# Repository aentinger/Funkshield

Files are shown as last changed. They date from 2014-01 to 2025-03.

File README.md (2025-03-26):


💾 Funkshield
==============



# 📸 Image

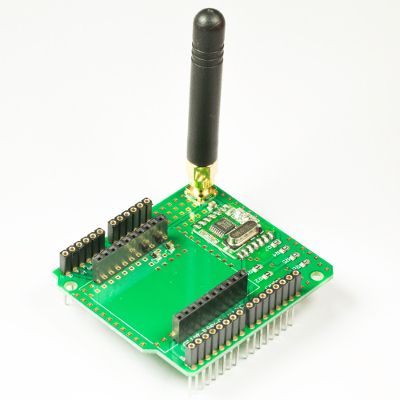
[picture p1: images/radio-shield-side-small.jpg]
LXRobotics P6 Funkshield


# 📂 Description

The Radio Shield provides an easy way to enable wireless communication between two or more Arduinos. Additionally the Radioshield has a Childboard connector socket which allows the Radio Shield to be further upgraded with sensors/actuators, e.g. a gas sensor, temperature sensor or a relay switch. A possible application would be temperature monitoring of all rooms of a house/appartment and performing an efficient regulation of the heating based on the measured data. For an quick and easy start, a open source Arduino library with sample programs is available.

**Features**

* Enables easy wireless communication with other Arduinos
* Usage of the popular RFM12B HF-Transceiver
* Frequency range: 433 MHz ISM-Band
* Childboard-Base for integration of further LXRobotics Childboards (e.g. gas sensor, temperature sensor, relay switch)
* Antenna with 2dbi gain
* Output power is selectable in 3 db steps ranging from 0 dbm to -21 dbm
* Third-Party-Arduino Library available for control with example programms

# 🎥 [Video](images/funkshield_demo.mp4)

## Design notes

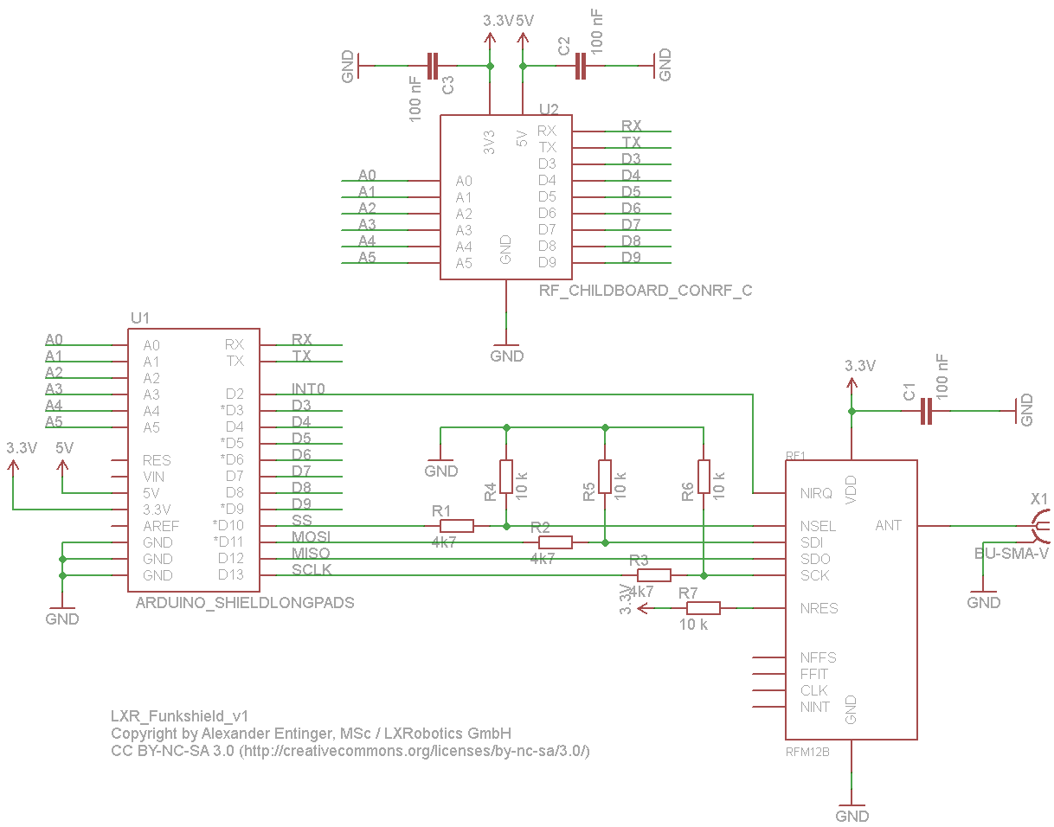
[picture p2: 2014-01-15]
hardware/lxr_funkshield_v1.png

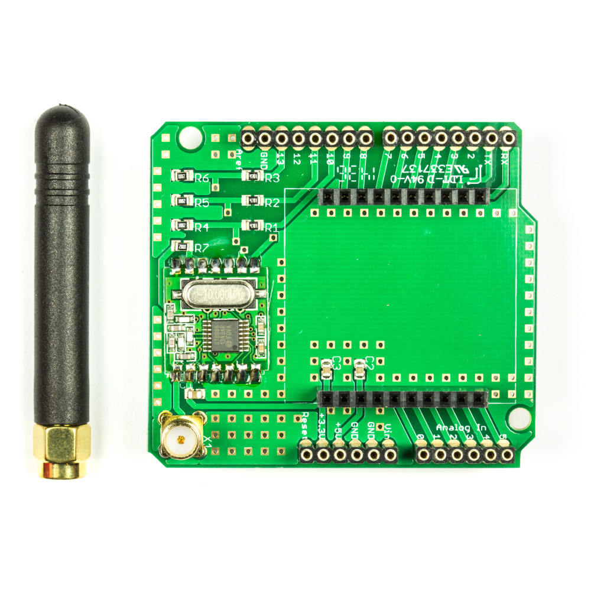
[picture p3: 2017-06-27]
images/radio-shield-top-large.jpg

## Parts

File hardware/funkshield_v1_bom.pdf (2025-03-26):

Menge | Schaltplan | Bezeichnung | Farnell/Conrad Bestell Nummer | Preis (1 Stück) | Gesamtpreis | Wird bestückt | Footprint | Säckchen
1 | RF1 | RFM12B-Klon RF SOLUTIONS - ALPHA-TRX433S | 1718689 | € 5,88 | € 5,88 | | | S1
1 | | 433 MHz Stab-Antenne kurz | 2305893 | € 4,88 | € 4,88 | | | S2
1 | X1 | SMA-Buchse für Leiterplattenmontage | 1248990 | € 1,83 | € 1,83 | | | S2
3 | R1, R2, R3 | 4k7, 0805, SMD Widerstand | 1469923 | € 0,02 | € 0,07 | x
4 | R4, R5, R6, R7 | 10k, 0805, SMD Widerstand | 1469856 | € 0,02 | € 0,09 | x
3 | C1, C2, C3 | 100 nF, 0805, SMD Kondensator | 1759144 | € 0,01 | € 0,03 | x
2 | U2 | RF Childboard Connector Female | 1593464 | € 1,52 | € 3,04 | | | S2
1 | Satz Arduino Stiftleisten | ELV | € | 0,75 | € | 0,75 | S2 | http://www.elv.at/buchsenleisten-set-fuer-arduino-boards.html
| | | Summe | | € | 16,57

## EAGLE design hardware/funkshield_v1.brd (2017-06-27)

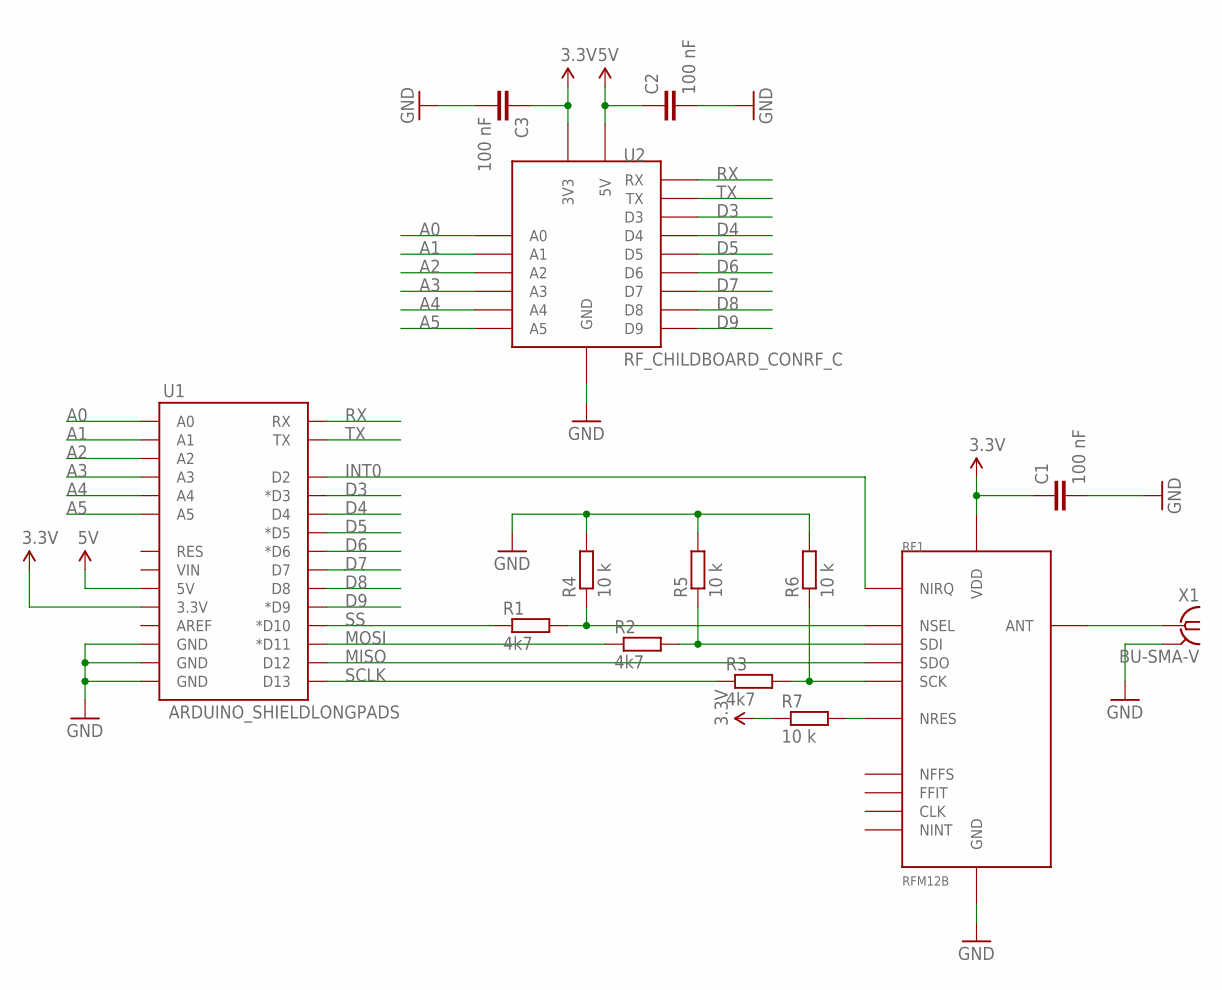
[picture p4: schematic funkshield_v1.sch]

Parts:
C1, C2, C3: 100 nF; C0805
R1, R2, R3: 4k7; M0805
R4, R5, R6, R7: 10 k; M0805
RF1: RFM12B
U1: ARDUINO_SHIELDLONGPADS; DUEMILANOVE_SHIELD_LONGPADS
U2: RF_CHILDBOARD_CONRF_C; RF_CHILDBOARD_CON
X1: BU-SMA-V

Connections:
3.3V: C1.1, C3.1, R7.1, RF1.VDD, U1.3.3V, U2.3V3
5V: C2.1, U1.5V, U2.5V
A0: U1.A0, U2.A0
A1: U1.A1, U2.A1
A2: U1.A2, U2.A2
A3: U1.A3, U2.A3
A4: U1.A4, U2.A4
A5: U1.A5, U2.A5
D3: U1.D3 (*D3), U2.D3
D4: U1.D4, U2.D4
D5: U1.D5 (*D5), U2.D5
D6: U1.D6 (*D6), U2.D6
D7: U1.D7, U2.D7
D8: U1.D8, U2.D8
D9: U1.D9 (*D9), U2.D9
GND: C1.2, C2.2, C3.2, R4.2, R5.2, R6.2, RF1.GND, RF1.GND1 (GND), U1.GND@0 (GND), U1.GND@1 (GND), U1.GND@2 (GND), U2.GND, U2.GND1 (GND), U2.GND2 (GND), X1.2 (GND), X1.3 (GND), X1.4 (GND), X1.5 (GND)
INT0: RF1.NIRQ, U1.D2
MISO: RF1.SDO, U1.D12
MOSI: R2.1, U1.D11 (*D11)
unnamed: R1.2, R4.1, RF1.NSEL
unnamed: R2.2, R5.1, RF1.SDI
unnamed: R3.2, R6.1, RF1.SCK
unnamed: R7.2, RF1.NRES
unnamed: RF1.ANT, X1.1
RX: U1.RX, U2.RX
SCLK: R3.1, U1.D13
SS: R1.1, U1.D10 (*D10)
TX: U1.TX, U2.TX

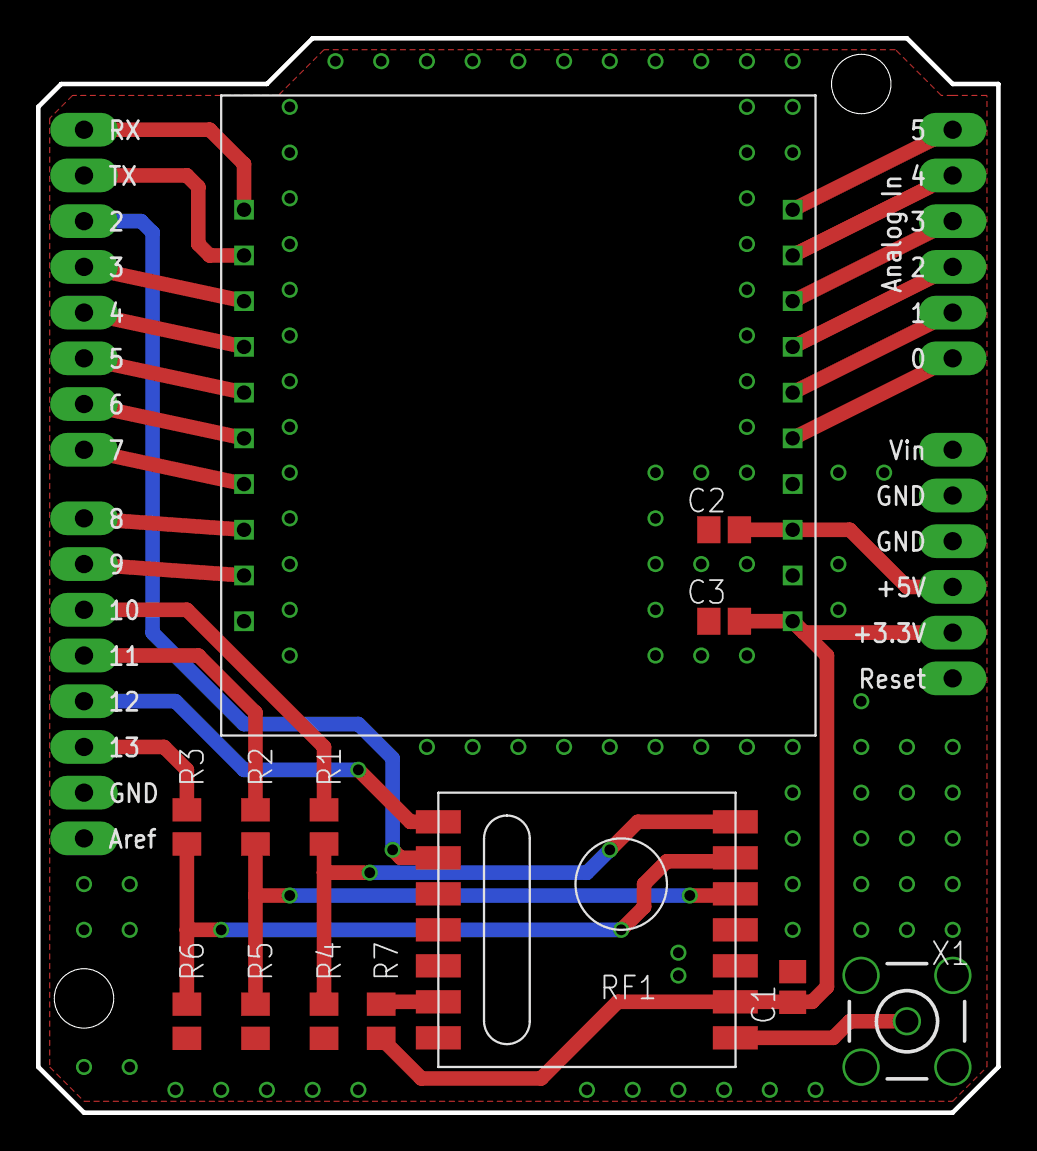
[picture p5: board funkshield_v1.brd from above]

Board: 2 copper layers, 53.3 x 59.7 mm, 14 parts (0 on the bottom side), 28 nets.

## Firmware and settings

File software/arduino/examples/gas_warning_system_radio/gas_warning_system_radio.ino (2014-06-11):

/** 
 * @author Alexander Entinger MSc, LXRobotics
 * @brief this file demonstrates how to use the LXR_CB_Gas_Sensor library in combination with an lxrobotics funkshield too form a wireless gas warning system network - Attention: This is not a calibrated nor a certified smoke/gas/whatever detector. Therefor it can never replace a "real" smoke/gas/.. warning system.
 * @file gas_warning_system_radio.ino
 * @license Attribution-NonCommercial-ShareAlike 3.0 Unported (CC BY-NC-SA 3.0) ( http://creativecommons.org/licenses/by-nc-sa/3.0/ )
 */

#include "LXR_CB_Gas_Sensor.h"
#include "RFM12B.h"
#include "avr/sleep.h"

#define NODEID        1  // Network ID of this unit -> Needs to be different for every node 0 to 127
#define NETWORKID    99  // Network ID
#define GATEWAYID     0  // BROADCAST

// Need an instance of the Radio Module
RFM12B radio;

void setup() {               
  // initialize the gas sensor childboard 
  LXR_CB_Gas_Sensor::begin();
  // turn on the gas sensor
  LXR_CB_Gas_Sensor::turn_on_sensor();
  // initialize radio
  radio.Initialize(NODEID, RF12_433MHZ, NETWORKID);
  // put radio to sleep to save power
  radio.Sleep();

}

static int const threshold = 300;

static uint8_t const alarm_on_payload = 0xAA;

void loop() {
  // check if there is gas in the room and if thats the case, send an alarm message
  if(LXR_CB_Gas_Sensor::read_gas_sensor() > threshold) {
    LXR_CB_Gas_Sensor::turn_on_led();
    LXR_CB_Gas_Sensor::turn_on_alarm();
    radio.Send(GATEWAYID, &alarm_on_payload, 1, false); // send the alarm message out
  } 

  // if a package was received, check if it was an alarm package
  if (radio.ReceiveComplete()) {
    if (radio.CRCPass()) {
      if(radio.GetDataLen() == 1) {
        if(radio.Data[0] == alarm_on_payload) {
          LXR_CB_Gas_Sensor::turn_on_led();
          LXR_CB_Gas_Sensor::turn_on_alarm();
        }
      }
    }
  }
  delay(100);
}

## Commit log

2017-06-27 Adding hardware + images
    [funkshield_v1.brd, funkshield_v1.sch]
2025-03-26 Add BOM.

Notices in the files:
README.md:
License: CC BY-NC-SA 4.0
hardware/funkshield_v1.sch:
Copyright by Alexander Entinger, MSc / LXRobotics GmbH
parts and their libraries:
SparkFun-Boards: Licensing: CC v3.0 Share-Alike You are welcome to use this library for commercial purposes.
